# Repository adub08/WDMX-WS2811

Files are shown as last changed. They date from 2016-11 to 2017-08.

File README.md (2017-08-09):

# WDMX-WS2811
This is the project home for the WDMX WS2811 controller. It's primarily designed for use as a wearable controller.
It Make's use of lib_dmx and FastLED ardunio libaries . It could in theroy be used to support non standard DMX protocals such as DMX1000K and other non-standard, high channel count DMX protocals (refer to the lib_dmx libary)
	
	Hardware Specs:
	•	Industry Standard wireless solution’s W-DMX header (compatible with internal or external antenna Nano boards & 2.4 or 5.8ghz)
	•	Standard WS2811 digital LEDs (and software adjustable to almost any NRZ [non-return-to-zero] digital LED protocol)
	•	5v or 7-24v DC input
	•	Battery voltage check mode
	•	Wired DMX input option
	•	Internal Temperature sensor
	•	Wired or Wireless RDM (Not implemented in software)
	•	Full SPI integration with the WDMX module (Not implemented in software)
	•	3 General Purpose digital I/O pins (2 interrupt compatible) with settable integrated hardware pull-ups, 1 ADC input pin
	•	2 LED headers (1 of which connects directly to the WDMX module)
	• 	Simple ardunio-compadible ISP programming  

	For More documentation please refer to Project Wiki

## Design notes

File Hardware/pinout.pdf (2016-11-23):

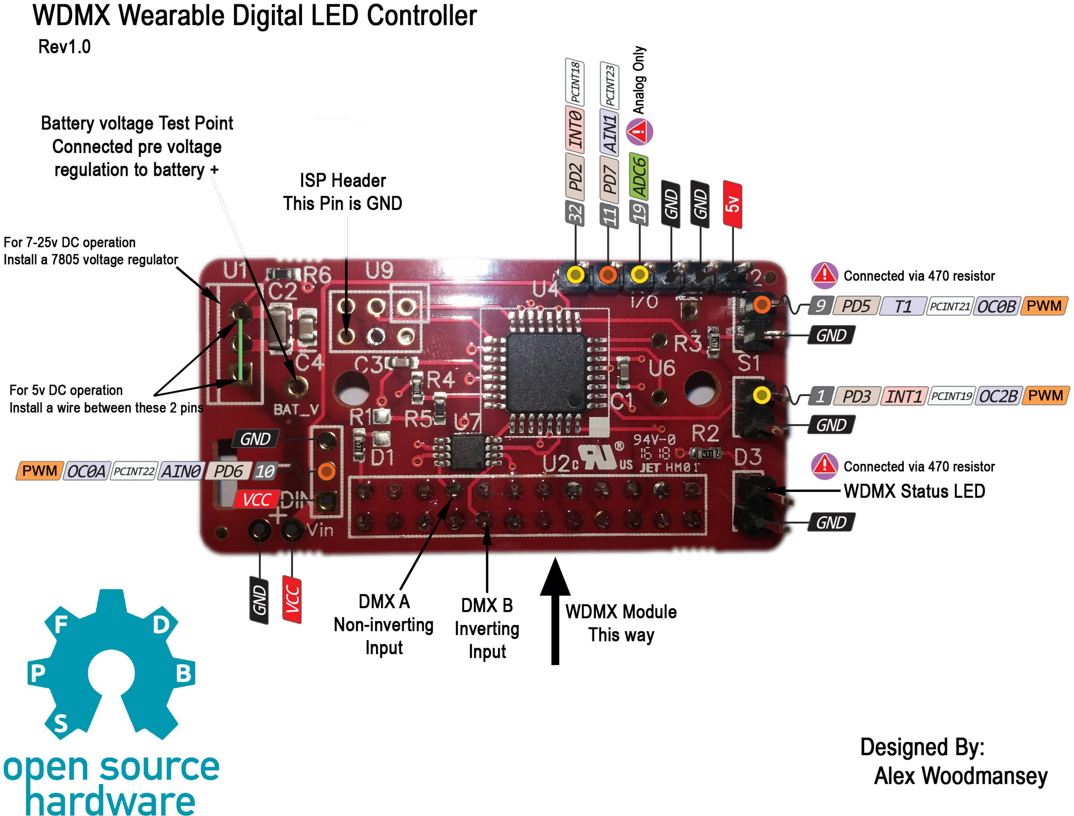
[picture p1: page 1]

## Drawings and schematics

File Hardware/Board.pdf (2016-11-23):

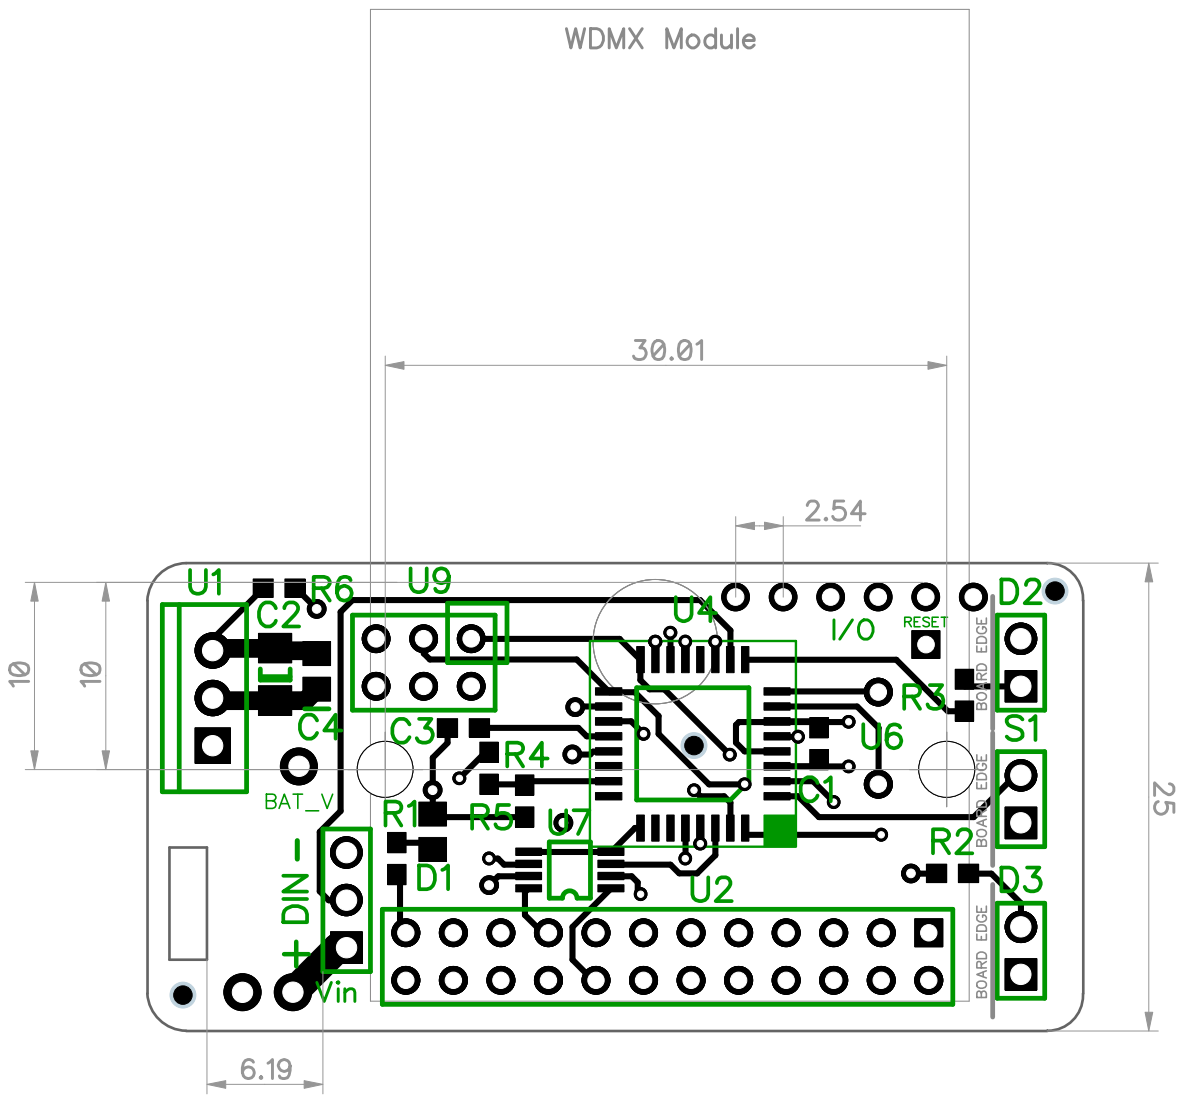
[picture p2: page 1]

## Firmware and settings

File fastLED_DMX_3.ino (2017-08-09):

//Written by Alex Woodmansey using Version 1.6.8 - 19-06-2016
#include "lib_dmx.h" //4 Universe DMX Library http://www.deskontrol.net/blog/arduino-four-universes-dmx-512-library/
#include "FastLED.h" //Fast LED Library https://github.com/FastLED/FastLED
#include <EEPROM.h>
#define    DMX512     (0)    // (250 kbaud - 2 to 512 channels) Standard USITT DMX-512
#define NUM_LEDS 11 //Number of LED Pixels connected
#define DATA_PIN 6  //Data Pin for LED Pixels
CRGB leds[NUM_LEDS]; //Define LED Array
#define COLOUR_ORDER RBG // LED colour order 

const int ledPin =  5;      // LED Pin 5 for DMX reception yes/no
const int testPin = 3;     // Switch Pin for Testing battery and panel
const int disconnectPin = 2; // switch pin to disconnect wdmx
const int WDMX_button = A5;     // Internal WDMX Button Pin
unsigned long now = 0; //current time value
const byte channelwidth = 3; //3 DMX channels per pixel
int channel; //channel number for each pixel RGB
volatile byte currentcounter = 0; //counter for DMX reception
byte previouscounter = 0; //counter for DMX reception 
byte current_hue; //hue value for rainbow effect
byte ledNumber; //current led Pixel being used 
volatile int val; //analog voltage from 



void setup() 
{ 
//  EEPROM.write(0, 1);   //Alternative addressing method by holding the DMX address in the EEPROM 
//  EEPROM.write(1, 64);
  ArduinoDmx0.attachRXInterrupt  (frame_received);  //set function called when all channels received
  ArduinoDmx0.set_control_pin (A2);    // control pin for max485   
  ArduinoDmx0.set_rx_address(1);      // set rx0 dmx start address
  ArduinoDmx0.set_rx_channels(NUM_LEDS*channelwidth);     // number of DMX channel to receive 
  ArduinoDmx0.init_rx(DMX512);        // starts universe 0 as rx, NEW Parameter DMX mode
  pinMode (ledPin, OUTPUT);  //status LED set to Output 
  pinMode (testPin, INPUT_PULLUP); //Test Mode Switch
  pinMode (WDMX_button, OUTPUT); //WDMX control button
  pinMode (disconnectPin, INPUT_PULLUP); //Disconnect interrupt switch
  digitalWrite(WDMX_button, HIGH); //WDMX control pin left high
  LEDS.setBrightness(255); //Set overall LED brightness
  FastLED.addLeds<WS2811, DATA_PIN, COLOUR_ORDER>(leds, NUM_LEDS); //initialize LED Pixel output
  attachInterrupt(digitalPinToInterrupt(disconnectPin), disconect, LOW);
  FastLED.setMaxPowerInVoltsAndMilliamps(12,1250);  //#experiemental# sets max power at 13.5w for LEDS
  

  post(); //run power on self test function each time board resets 
  SYS_TEST(); //Checks Battery voltage and displays over pixels
}  //end setup()

void loop()
{
  if(currentcounter != previouscounter) //has the value changed?
  {
    now = millis(); //store the time since the value has increased 
    previouscounter = currentcounter; //set the previous value equal to the current value
  }
  
  if((millis() - now) > 5000) //is the time since the value changed greater than 5 seconds?
  {
   digitalWrite(ledPin, LOW); //turn status LED off. We are no longer receiving the DMX signal.  
    noDMX(); //run no DMX function
  }
  else
  {
   digitalWrite(ledPin, HIGH); //turn status LED on.  We are receiving the DMX signal.
   DMXProcess(); //run DMX function
  }
  
}  //end loop()

// Custom ISR: fired when all DMX channels in one universe are received
void frame_received(uint8_t universe) 
{
  static uint8_t led;
  
  if (universe == 0) // USART0
  {
    currentcounter++;  //increase counter by 1 each time through 
  }
}  // end of ISR


void DMXProcess() //Function to process DMX data
{
channel = 0; //reset DMX channel assignment to 0 each time through loop. 
for(ledNumber = 0; ledNumber < NUM_LEDS; ledNumber++) //Counter for pixel number
{ 
leds[ledNumber]= CRGB(ArduinoDmx0.RxBuffer[channel], ArduinoDmx0.RxBuffer[channel +1], ArduinoDmx0.RxBuffer[channel +2]); //assign DMX channels to RGB channel of each pixel
channel +=channelwidth; //increase last DMX channel number by channel width
}
  FastLED.show(); //Send data to pixels
  delay(60); //delay 60 miliseconds for DMX to catch up.
} 

void noDMX() //Function to run when no DMX signal is present
{
    
    
  // fill 'leds' array with a rainbow, starting at
  // a slightly different color each time, to create motion.
  static uint8_t startIndex = 0;
  startIndex = startIndex + 1; /* higher = faster motion */

  fill_rainbow( leds, NUM_LEDS, startIndex);

  // tell FastLED to send the 'leds' buffer out to the
  // actual LEDs
  FastLED.show();
  
  // insert a delay to keep the framerate modest (eg, 60 FPS).
  // delay takes milliseconds, to 1000/60 = about 60 FPS.
  FastLED.delay(1000 / 60);

} //End noDMX

 void SYS_TEST() //Will show battery voltage on a scale of 0-1023 over 0-NUM_LEDs [requires calabration]
{
  FastLED.clear(); //take all LEDs to 0
  fill_solid( leds, NUM_LEDS, CRGB(255,255,255)); // All LEDs Full at white 
  FastLED.show();
  delay(300);
  int val = analogRead(0); //reads battery Voltage
  float numLedsToLight = val /3.487  ;
  FastLED.clear(); //take all LEDs to 0
 for(int led = 0; led < numLedsToLight; led++) { 
  leds[led] = CRGB::Green; 
 }
  FastLED.show();
  delay(10000);
}


void post() //power on self test function.  Make sure all pixels are working and run through colors.
{
   LEDS.showColor(CRGB(255, 0, 0)); //turn all pixels on red
   delay(1000);
   LEDS.showColor(CRGB(0, 255, 0)); //turn all pixels on green
   delay(1000);
   LEDS.showColor(CRGB(0, 0, 255)); //turn all pixels on blue
   delay(1000);
   LEDS.showColor(CRGB(0, 0, 0)); //turn all pixels off
   
}

 void disconect() //Disconnects WDMX module, currently runs within ISR - could be nicer. 
{
  digitalWrite(WDMX_button,LOW);
  delayMicroseconds(30000);
  delayMicroseconds(30000);
  delayMicroseconds(30000);
  delayMicroseconds(30000);
  digitalWrite(WDMX_button,HIGH);
}

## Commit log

2016-07-13 Rev 3.0
    Current In use revision. No RDM & no WDMX module SPI control. Signal Will hold after loss forever.
2016-11-19 Hardware PCB upload.
    Rev 1.1.
    ###Please note i have not had this version produced at a Fab yet, only the original rev1.0. however only cosmetic changes to the silkscreen has been changed. Use at your own risk!
    [BoardOutline.gbr, BottomMask.gbr, BottomSilk.gbr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]
2016-11-23 Gerbers Rev 0.6
    Please Note this revision has not yet been in production by me yet,
    however 0.5 was and only subtle changes have occured.
    [BottomMask.gbr, BottomSilk.gbr, Bottom[GND].gbr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]
2017-08-09 Fixes made
    Fixes made + Improved notation
    [fastLED_DMX_3.ino]
2017-09-07 Remove Hardware
    [BoardOutline.gbr, BottomMask.gbr, BottomSilk.gbr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]
2021-10-23 Uploaded hardware rev1.0 gerbers
    [BoardOutline.gbr, BottomMask.gbr, BottomSilk.gbr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]
